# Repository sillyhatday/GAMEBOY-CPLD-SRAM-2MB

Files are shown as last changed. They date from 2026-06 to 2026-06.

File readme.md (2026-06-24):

# GAMEBOY-CPLD-SRAM-2MB

>[!WARNING]
>Current circuit board revision does not include support for the MAX7000 or ATF150x CPLD without bodges.

## Introduction:

This is my take of a CPLD based flash cart for the Gameboy.

The whole project is based from Alex's project from years back. Without that project, I would never have picked this up and spend my time figuring out how to work with CPLDs. I am not a programmer and do not claim to be. Picking up Alex's code I can see how things work with my previous knowledge of how carts operate.

This version uses SRAM like Alex's did originally. As much as I love using FRAM to bring this old technology towards the modern age, it is technically not compatible due to timing and different glue logic requirments. Not to mention it's really expensive new, China sells cheap factory rejects, and on the whole it's a pain in the ass. Embrace SRAM, it's cheap and available. The battery life is not an issue as people want to think, my original Pokemon Red, Blue and Yellow carts are still using the original batteries with over 3v in them after 28 years.

The newest update has been done with the help of AI. I just wanted to get this thing done so it is off my active project list. Even though AI has helped, I have learned a little bit more about how CPLDs work because of it. In the future I'd like to use the knowledge to do another project.

Some reasons to build this project are:

	+ No need for sourcing a donor cartridge
	+ Multi MBC compatibility
	+ Cheaper to build vs a donor cart (initially not, more made, more saved)
	+ No messing with expensive FRAM or dodgy back ally FRAM

>[!IMPORTANT]
> This project is designed with MBC5 functionality as the main priority. Compatibility with MBC1 is added on top, therefore, compatibility is not guaranteed. Super Mario Land 2 & Zelda: Link's Awakening work here, where they have issues running on a normal MBC5 chip. However, Donkey Kong Land does not work. Maybe one day I can create an MBC1 CPLD mapper.

>[!NOTE]
>For updates, see towards the end of the readme

## 🟦 Project State:

### :green_circle: Done

	- Get a cartridge that works well enough
	- Make the Altera 3032A & 3064A both work
	- Fix SRAM problems with MAX7000 and edge case MAX3000
	- Fix this readme after half updating and rage quitting. Remove V2.0 PCB pics.
	- Write draft of instructions for programming Atmel chips

### :yellow_circle: In Progress

	- Do some power tests of carts I have built so far.

### :white_circle: To Do

	- Test flashing Atmel chips in circuit
	- Design some hardware to flash Atmel chips in circuit
	- Update PCB to include solder jumper for different CPLD families.
	- Some issues with SRAM in FlashGBX with Atmel 1502A. Check hardware over & adjust WinCUPL settings.

## 🟨 Prerequisites

	* The full components parts list and cart PCB
	* (Optional) JTAG adaptor PCB
	* Altera USB Blaster or FT232 for JTAG (cheap clones work)
	* Windows PC with Quartus II Programmer, Quartus II Web Edition or OpenOCD
	* GBxCart and related software
 	* Modified Gameboy cart shell or (optional) 3D printed Game Gear cart adaptor
	* Equipment to solder tiny SMD components
	* Skills to solder tiny SMD components reliably

## 🔌 CPLD Information

>[!TIP]
>Information on chosing a CPLD <br>
>[ALTERA PROGRAMMING GUIDE](AlteraProgrammingGuide.md) <br>
>[ATMEL PROGRAMMING GUIDE](AtmelProgrammingGuide.md) <br>
>[CPLD POWER USAGE](CartPowerUse.md) <br>

Prices vary, these are typical.

| Model | Cost x1 | Vendor |
| ----- | --- | --- |
| 3032A: | €1.16 | Aliexpress |
| 3064A: | €1.60 | Aliexpress |
| 7032S: | €1.85 | Aliexpress |
| 1504A: | €1.97 | Mouser |

Depending on the model, the AP2127K-3.3TRG1 may not be needed.

| Model | AP2127K | Jumper |
| ----- | --- | --- |
| 3032A | YES | NO |
| 3064A | YES | NO |
| 7032S | NO | YES |
| 1502A | NO | YES |

## 🟦 Parts List

### Cartridge x1

>[!IMPORTANT]
>When ordering cartridge PCBs, make sure to choose 0.8mm thickness and gold plating. <br>
>Altera MAX3000 & MAX7000 CPLDs are obselete and only found on Aliexpress. I suggest the 3032A. (MAX7000 is a relic at this point). <br>
>If ordering MAX7000, get the S version, otherwise throw your money in a fire. Eg, EPM7032S <br>
>Atmel ATF150x parts can be bought new from reputable sellers. However they are trickier to program for the average person. <br>
>Order FRAM from Aliexpress & eBay at your own risk, they are known to be ***extremely*** unreliable. <br>

| Part No. | Package | Qty |
| --- | --- | --- |
| 29F016 | TSOP48 | 1 |
| IS62C256* | SOIC28 | 1 |
| CPLD** | TQFP44 | 1 |
| AP2127K-3.3TRG1*** | SOT23-5 | 1 |
| TPS3613-01DGSR | 10VSSOP | 1 |
| 2N7002 | SOT23 | 1 |
| Cap 100nF | 0603 | 5 |
| Cap 1uF | 0603 | 1 |
| Res 10K | 0603 | 1 |
| Res 49K9 | 0603 | 1 |
| Res 130K | 0603 | 1 |
| Bat Holder | AliExp | 1 |

**Other alternatives include, but are not limited to: AS6C6256, CY62256, R1LP5256. <br>
***EPM3064A, EPM3032A, EPM7064S, EPM7032S, ATF1504A or ATF1502A. <br>
****See CPLD info*

### JTAG Adaptor

| Part No. | Qty |
| --- | --- |
| DS Lite Cart Conn | 1 |
| USB C USB4125 | 1 |
| Pin Headers | 2x5-P2.54mm |
| GG Adaptor or Shell | 1 |
| USB Blaster | 1 |

>[!TIP]
>Link to [Game Gear Adaptor](https://www.thingiverse.com/thing:5830799)

## Build Photos

CPLDcartcomp

**Different CPLD** <br>
CPLDcartclose

## Update June 2026

I've picked this back up again when I found a PCB laying about. I had to wonder if AI was good enough now to help improve things. It is fortunately.

The previous update I was naive to think programming in C++ was anything like Verilog. I mean it is, but the device being programmed works so differently to other CPU based systems.

The issue that has been plaguing the 7032S & 1504A, is the save RAM functionality. Games would not save, or correctly use the cartridge as work RAM. This was on the Gameboy and cart readers. I tested this over a few carts and the first one kinda worked. It was flaky but saving, yet only on the GB and not the cart reader. There worst problem is that this problem crept into some of the 3032A and 3064A carts also.

This code refactor seems to have fixed all these problems, not only the MAX3000 but the MAX7000 also. As of now, the ATF1504 is untested. I am hopeful that it will work also. Programming those is more complex and I've since forgotten how to do it.

The smaller EPM3032A, EPM7032S & ATF1502 with 32 macro cells are now more than big enough to fit the program, no longer is it so tight. This is thanks to removing the 128KB RAM functionality, reducing the amount of registers required to address that has gained a lot of space. Additional code can be added for more functionality such as moving the FRAM gate logic into the CPLD and making it user programmable with a solder bridge on the PCB.

This is all very nice as the smaller chips tend to use less power than the larger counterparts, even though they use the same quantity of macro cells. I'll add more detailed information on the changes in its own readme.

When the Atmel part is confirmed working, I'll update the rest of the readme to walk though programming those. Ideally the PCB could use a revision to add the FRAM mode jumper and a jumper to bypass the 3.3v regulator when using the MAX7000 and ATF15xx chips. Again, I'll get to that when testing is complete.

## Firmware Versions

| Version | Status | Notes |
| --- | --- | ----- |
| V1.0.0  | Initial | Original code from Alex's blog |
| V1.0.1  | Fix | Removed internal FRAM chip select logic to lower cartridge power consumption 1 to 3% |
| V2.0.0  | Fix | Changed project compiler settings to lower cartridge power consumption 36 to 41% |
| V3.0.0  | Current | AI helper to teach me and structure code better. Use of macro cells more efficient. Logic split into smaller sections. More reliable, cleaner code, better output waveforms (I need to confirm that). |

## 🩷 Links

🔧 Driver Install: https://www.terasic.com.tw/wiki/Intel_USB_Blaster_Driver_Installation_Instructions <br>
⬇️ Driver Download: https://github.com/sudhamshu091/USB-Blaster-Driver-for-DE10-lite <br>
🖨️ Game gear Adaptor: https://www.thingiverse.com/thing:5830799 <br>
⏬ Alt Link Quartus: https://archive.org/details/quartus-iiprogrammer-and-signal-tap-ii-13.1.0.162.7z <br>
🛍️ Inside Gadgets Shop: https://shop.insidegadgets.com <br>
📎 Inside Gadgets GitHub: https://github.com/insidegadgets <br>
📷 Inside Gadgets Insta: https://www.instagram.com/inside.gadgets <br>
🖇️ Bytendo Mods GitHub: https://github.com/bytendomods <br>
🐭 Bucket Mouse: https://github.com/Bucket-Mouse <br>
🛒 Natalie Shop: https://nataliethenerd.com/ <br>
🤓 Natalie GitHub: https://github.com/natalie-lang/natalie <br>

Thanks to Xukkorz, Drew, Jamo, Alex, Deceptive Thinker, Natalie the Nerd & anyone else who I may have forgotten.

## License

This work is licensed under a Creative Commons Attribution-ShareAlike 4.0 International License. You are able to copy and redistribute the material in any medium or format, as well as remix, transform, or build upon the material for any purpose (even commercial) - but you must give appropriate credit, provide a link to the license, and indicate if any changes were made.

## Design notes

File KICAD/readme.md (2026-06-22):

I never uploaded the pcb files wtf. I think these are up to date.

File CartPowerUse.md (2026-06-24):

## 🔌 Cartridge Power:

>[!NOTE]
>I cut the 5V plane coming from the 5v cart pin and bridged it with a 2.2Ω shunt resistor. Voltage was then measured accross the resistor to determine current used.
>These are screen captures from an emulator to show the game locations used for testing more clearly than photographs of the Gameboy screen:

First 4 caps
2nd 4 caps
Stats

## Altera EPM3064A:

| Pokemon Shin Red | Current mA V1.0 | Current mA V1.1 | Current mA V2.0 | Current mA V3.0 |
| --- | --- | --- | --- | --- |
| Intro Animation  | 30.9 | 31 | 17 | 26.4 |
| Title Screen Low | 30.3 | 30.2 | 17.6 | --- |
| Title Screen High | 35.8 | 35.7 | 23.9 | 30.9 |
| Overworld A | 32.7 | 33.1 | 21.3 | 28.4 |
| Overworld B | 30.2 | 30.5 | 18.9 | 26.1 |
| Overworld Talking | 38.7 | 38.9 | 27.6 | 33.6 |
| Pokemon Centre Nurse | 38.6 | 38.7 | 27.4 | 33.6 |
| Battle Scene | 34.8 | 34.8 | 23.3 | 30.3 |
| Pause Menu | 38.5 | 38.5 | 26.7 | 33.2 |
| Pokemon Stats | 38.7 | 38.7 | 27.1 | 33.5 |
| Average | 34.9 | 35.0 | 23.1 | 30.7 |

## Altera EPM3032A:

| Pokemon Shin Red | Current mA V1.0 | Current mA V1.1 | Current mA V2.0 | Current mA V3.0 |
| --- | --- | --- | --- | --- |
| Intro Animation | 26.4 | 25.8 | 15.9 | 17.2 |
| Title Screen Low | 25.9 | 25.1 | 15.6 | --- |
| Title Screen High | 31.8 | 30.1 | 20.9 | 23.9 |
| Overworld A | 29.0 | 28.1 | 18.5 | 20.2 |
| Overworld B | 26.5 | 25.6 | 16.4 | 17.8 |
| Overworld Talking | 34.9 | 34.1 | 24.5 | 26.2 |
| Pokemon Centre Nurse | 34.9 | 34.1 | 24.3 | 26.2 |
| Battle Scene | 31.2 | 30.3 | 20.9 | 22.7 |
| Pause Menu | 34.7 | 33.8 | 24.0 | 25.9 |
| Pokemon Stats | 35.0 | 34.1 | 24.2 | 26.4 |
| Average | 31.0 | 30.1 | 20.5 | 22.9 |

## Altera EPM7032S:

| Pokemon Shin Red | Current mA V1.0 | Current mA V1.1 | Current mA V2.0 | Current mA V3.0 |
| --- | --- | --- | --- | --- |
| Intro Animation | ---- | 34.6 | 21.8 | 20.2 |
| Title Screen Low | ---- | 34.2 | 21.6 | ---- |
| Title Screen High | ---- | 51.0 | 46.4 | 27.8 |
| Overworld A | ---- | 37.1 | 24.9 | 23.7 |
| Overworld B | ---- | 34.7 | 22.7 | 21.2 |
| Overworld Talking | ---- | 52.9 | 41.3 | 30.2 |
| Pokemon Centre Nurse | ---- | 53.0 | 41.3 | 29.7 |
| Battle Scene | ---- | 39.7 | 27.9 | 26.3 |
| Pause Menu | ---- | 42.9 | 30.9 | 29.7 |
| Pokemon Stats | ---- | 43.0 | 30.9 | 30.1 |
| Average | ---- | 42.3 | 31.0 | 26.5 |

## Atmel ATF1502A:

| Pokemon Shin Red | Current mA V1.0 | Current mA V1.1 | Current mA V2.0 | Current mA V3.0 |
| --- | --- | --- | --- | --- |
| Intro Animation | ---- | ---- | 36.8 | 40.0 |
| Title Screen Low | ---- | ---- | 36.6 | ---- |
| Title Screen High | ---- | ---- | 55.9 | 47.7 |
| Overworld A | ---- | ---- | 39.8 | ---- |
| Overworld B | ---- | ---- | 37.6 | ---- |
| Overworld Talking | ---- | ---- | 55.9 | ---- |
| Pokemon Centre Nurse | ---- | ---- | 56.0 | ---- |
| Battle Scene | ---- | ---- | 42.7 | ---- |
| Pause Menu | ---- | ---- | 45.5 | 47.9 |
| Pokemon Stats | ---- | ---- | 46.3 | 48.1 |
| Average | ---- | ---- | 46.0* | 45.9** |

>[!NOTE]
>**Buggy and strange flashing behaviour* <br>
>***RAM refuses to flash properly under sustained writes* <br>

## Summary

I did not expect the MAX3000 chips to get worse with a *better* firmware. It's not a huge difference, but it is there. I also did not expect the MAX7000 to get better! There is obviously some architecture differences that favour the older ***long*** obselete MAX7000 series.

The unfortunate data comes from the Atmel chips. I was hopeful these would be competative with the others as they are the only readily availible items. Not only have I had endless troubles getting save RAM to work properly, the amount of power used is too high. For example, a stock DMG running a stock Pokemon Blue cart uses between 44 - 60mA for the entire console...

The clear winner is the 3032A, with the lowest power use and it also being the cheapest to purchase.

Second place is a tie between the 3064A and 7032S. While the 3064A is the cheaper of the two, the 7032S is better on power. I call it a draw as the 7032S doesn't cost a lot more than the 3064A.

Last place its the 1502A with awful power draw, highest price, harder to program and still not fully working.

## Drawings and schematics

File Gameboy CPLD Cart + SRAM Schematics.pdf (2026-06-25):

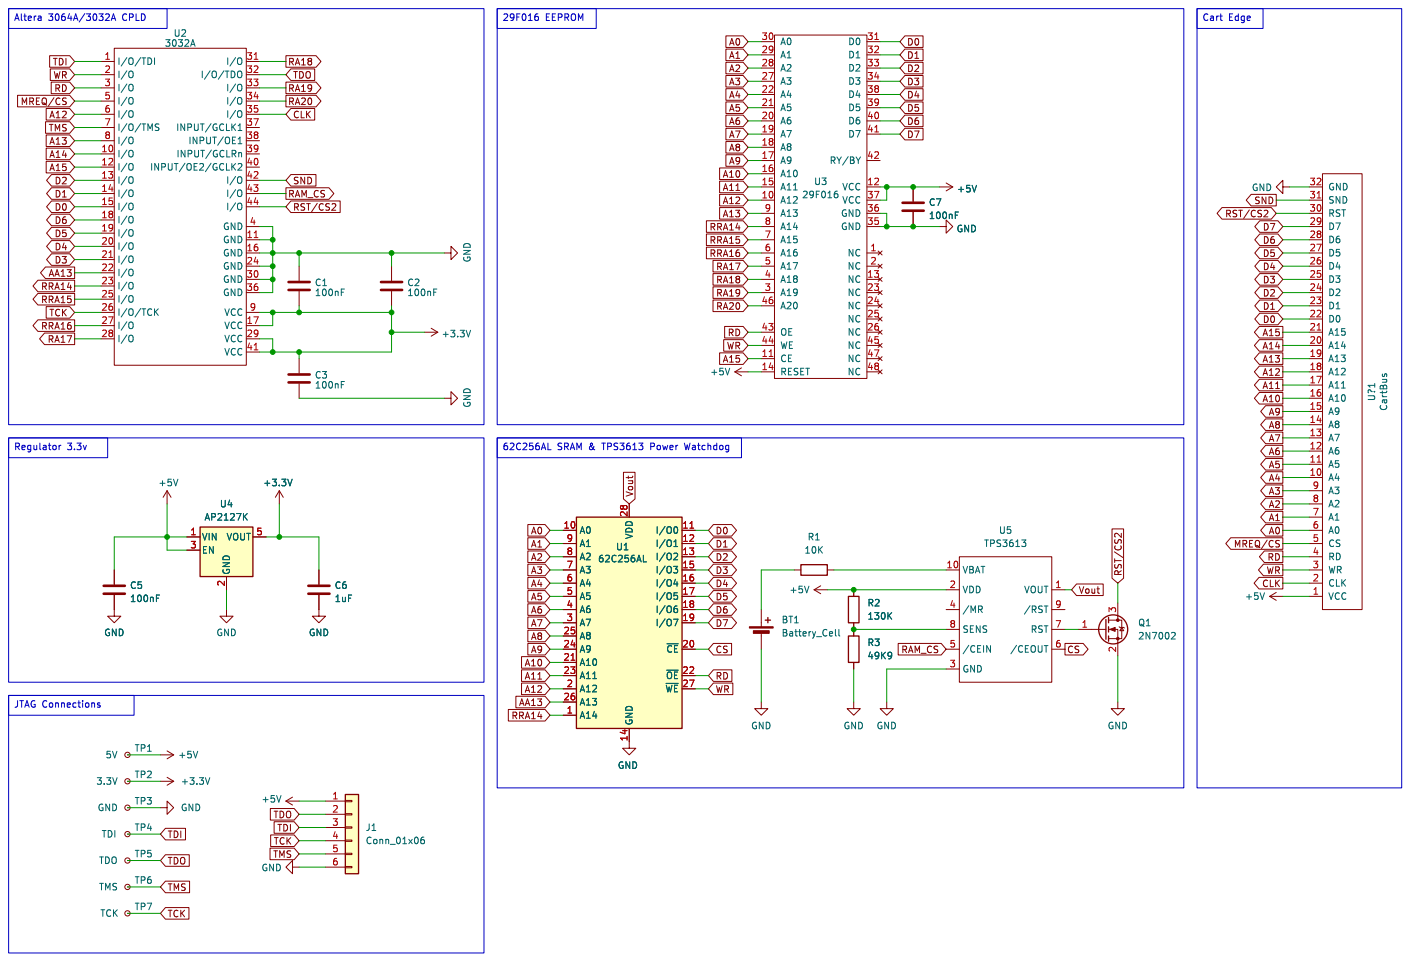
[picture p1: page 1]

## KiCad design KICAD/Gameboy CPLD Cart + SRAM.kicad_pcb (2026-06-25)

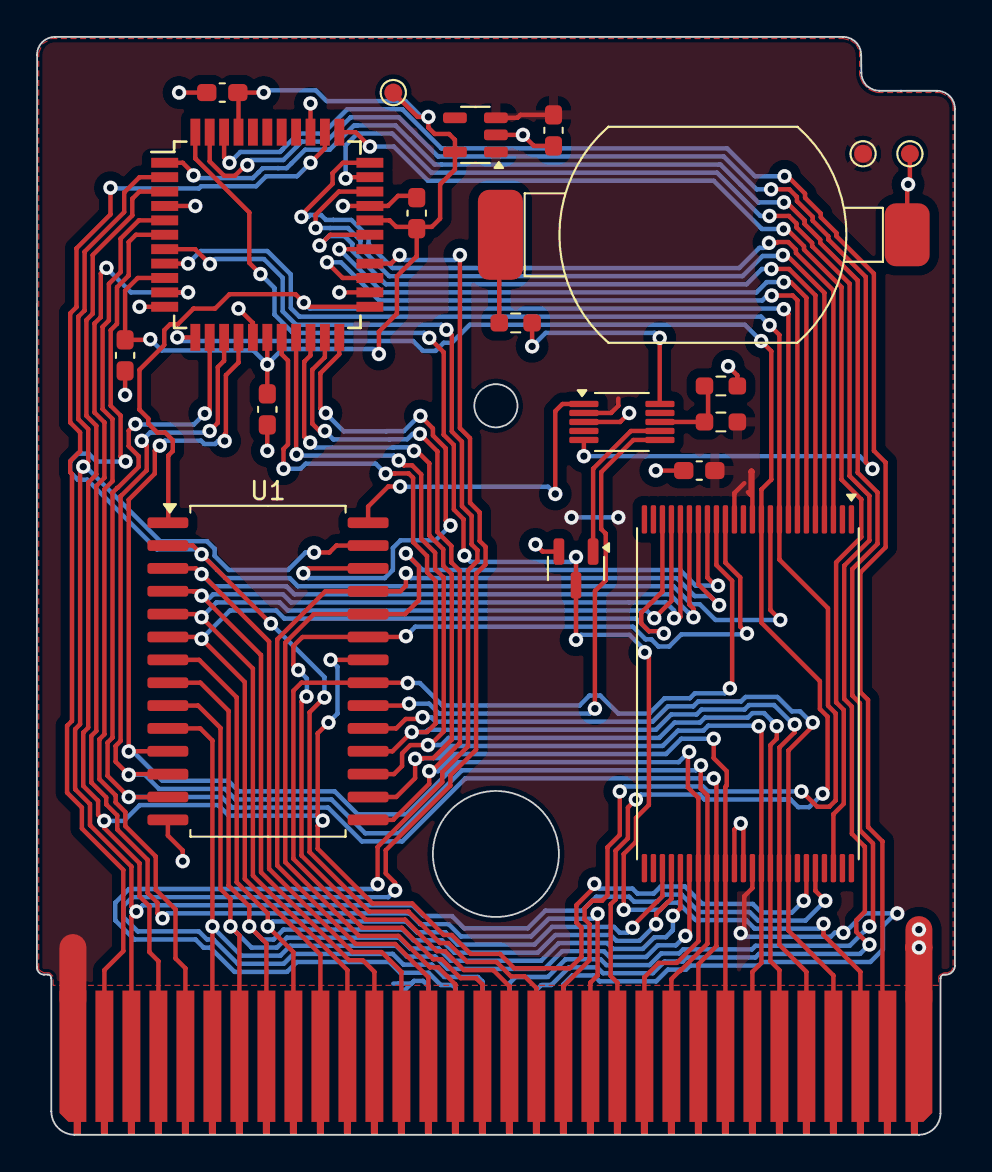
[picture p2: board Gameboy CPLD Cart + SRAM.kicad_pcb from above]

Board: 2 copper layers, 51.0 x 61.0 mm, 21 parts (1 on the bottom side), 52 nets.

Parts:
BT1: Battery_Cell; CR1616 CLIP IN HOLDER
C1, C2, C3, C5, C7: 100nF; C_0603_1608Metric_Pad1.08x0.95mm_HandSolder
C6: 1uF; C_0603_1608Metric_Pad1.08x0.95mm_HandSolder
J1: Conn_01x06; JTAG Cart Edge Connector
Q1: 2N7002; SOT-23
R1: 10K; R_0603_1608Metric_Pad0.98x0.95mm_HandSolder
R2: 130K; R_0603_1608Metric_Pad0.98x0.95mm_HandSolder
R3: 49K9; R_0603_1608Metric_Pad0.98x0.95mm_HandSolder
TP1: 5V; TestPoint_Pad_D1.0mm
TP2: 3.3V; TestPoint_Pad_D1.0mm
TP3: GND; TestPoint_Pad_D1.0mm
U1: 62C256AL; SOP-28_8.4x18.16mm_P1.27mm
U2: 3032A; TQFP-44_10x10mm_P0.8mm
U3: 29F016; TSOP-I-48_18.4x12mm_P0.5mm
U4: AP2127K; SOT-23-5
U5: TPS3613; MSOP-10_3x3mm_P0.5mm
U?1: CartBus; GameBoy_GamePak_DMG-09_P1.50mm_Edge

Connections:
+3.3V: C1.1, C2.1, C3.2, C6.1, TP2.1, U2.9 (VCC), U2.17 (VCC), U2.29 (VCC), U2.41 (VCC), U4.5 (VOUT)
+5V: C5.1, C7.1, J1.1, R2.1, TP1.1, U3.12 (VCC), U3.14 (RESET), U3.37 (VCC~), U4.1 (VIN), U4.3 (EN), U5.2 (VDD), U?1.1 (VCC)
A0: U1.10 (A0), U3.30 (A0~), U?1.6 (A0)
A1: U1.9 (A1), U3.29 (A1), U?1.7 (A1)
A2: U1.8 (A2), U3.28 (A2), U?1.8 (A2)
A3: U1.7 (A3), U3.27 (A3), U?1.9 (A3)
A4: U1.6 (A4), U3.22 (A4), U?1.10 (A4)
A5: U1.5 (A5), U3.21 (A5), U?1.11 (A5)
A6: U1.4 (A6), U3.20 (A6), U?1.12 (A6)
A7: U1.3 (A7), U3.19 (A7), U?1.13 (A7)
A8: U1.25 (A8), U3.18 (A8), U?1.14 (A8)
A9: U1.24 (A9), U3.17 (A9), U?1.15 (A9)
A10: U1.21 (A10), U3.16 (A10), U?1.16 (A10)
A11: U1.23 (A11), U3.15 (A11), U?1.17 (A11)
A12: U1.2 (A12), U2.6 (I/O), U3.10 (A12), U?1.18 (A12)
A13: U2.8 (I/O), U3.9 (A13), U?1.19 (A13)
A14: U2.10 (I/O), U?1.20 (A14)
A15: U2.12 (I/O), U3.11 (CE), U?1.21 (A15)
AA13: U1.26 (A13), U2.22 (I/O)
CLK: U2.35 (I/O), U?1.2 (CLK~)
CS: U1.20 (~CE), U5.6 (/CEOUT)
D0: U1.11 (I/O0), U2.15 (I/O), U3.31 (D0), U?1.22 (D0)
D1: U1.12 (I/O1), U2.14 (I/O), U3.32 (D1), U?1.23 (D1)
D2: U1.13 (I/O2), U2.13 (I/O), U3.33 (D2), U?1.24 (D2)
D3: U1.15 (I/O3), U2.21 (I/O), U3.34 (D3), U?1.25 (D3)
D4: U1.16 (I/O4), U2.20 (I/O), U3.38 (D4), U?1.26 (D4)
D5: U1.17 (I/O5), U2.19 (I/O), U3.39 (D5), U?1.27 (D5)
D6: U1.18 (I/O6), U2.18 (I/O), U3.40 (D6), U?1.28 (D6)
D7: U1.19 (I/O7), U3.41 (D7), U?1.29 (D7)
GND: BT1.2 (-), C1.2, C2.2, C3.1, C5.2, C6.2, C7.2, J1.6, Q1.2 (S), R3.2, TP3.1, U1.14 (GND), U2.4 (GND), U2.11 (GND), U2.16 (GND), U2.24 (GND), U2.30 (GND), U2.36 (GND), U3.35 (GND), U3.36 (GND), U4.2 (GND), U5.3 (GND), U?1.32 (GND)
MREQ/CS: U2.5 (I/O), U?1.5 (CS)
unnamed: BT1.1 (+), R1.1
unnamed: Q1.1 (G), U5.7 (RST)
unnamed: R2.2, R3.1, U5.8 (SENS)
unnamed: R1.2, U5.10 (VBAT)
RA17: U2.28 (I/O), U3.5 (A17)
RA18: U2.31 (I/O), U3.4 (A18)
RA19: U2.33 (I/O), U3.3 (A19)
RA20: U2.34 (I/O), U3.46 (A20)
RAM_CS: U2.43 (I/O), U5.5 (/CEIN)
RD: U1.22 (~OE), U2.3 (I/O), U3.43 (OE~), U?1.4 (RD)
RRA14: U1.1 (A14), U2.23 (I/O), U3.8 (A14)
RRA15: U2.25 (I/O), U3.7 (A15)
RRA16: U2.27 (I/O), U3.6 (A16)
RST/CS2: Q1.3 (D), U2.44 (I/O), U?1.30 (RST)
SND: U2.42 (I/O), U?1.31 (SND)
TCK: J1.4, U2.26 (I/O/TCK)
TDI: J1.3, U2.1 (I/O/TDI)
TDO: J1.2, U2.32 (I/O/TDO)
TMS: J1.5, U2.7 (I/O/TMS)
Vout: U1.28 (VDD), U5.1 (VOUT)
WR: U1.27 (~WE), U2.2 (I/O), U3.44 (WE), U?1.3 (WR)

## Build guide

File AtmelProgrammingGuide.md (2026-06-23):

## Programming Atmel parts (DRAFT)

I'm going to do my best to document this. These Atmel parts are more involved to get working. There is also a save bug with larger save files that needs solving. I figured out how to do this once before and forgot, so spent hours figuring it out again. Nothing I do is ever easy or simple.

Firstly, for programming Atmel parts, Quartus Programmer is of no use. The program used in its place is `OpenOCD`. It's a command line/terminal program that is far from user friendly. It is a powerful tool, that means there are a lot of options to configure. I've bundled these options into a config file to help simplify things.

As with Altera parts, there needs to be some hardware to do the programming. I use a generic FT232H clone from Aliexpress. It was about £3. Right now this is the state of the programmer:

atmelflasher

I plan to do something to make this more user friendly. Firstly, make it so the chips can be flashed in circuit. The issue in making it more user friendly is that there are so many different FT232 clones that I can't make every one of them plug into the JTAG adaptor. I can make a separate board that the ribbon cable can plug into along with the FT232. That is more of the same problem with so many different FT232 clones. Plus, it's another PCB to make to add more expense and complication. I need to think.

>[!WARNING]
>I suggest doing this in Windows and not Linux. On Linux I've had problems talking to the FT232 due to the driver being held by something else. I think it's `brltty` but I gave up solving it.

Download OpenOCD. Move the program to a simple folder path like `C:\openocd` to make things easier when using the command line. Open this folder and go to the `bin` folder inside. This is where some files need to be placed. In here copy `prog.cfg` and the SVF file for the CPLD you are using.

That should be the software setup ready. Check if OpenOCD can talk to the FT232 device. If not, a new driver needs to be installed.

Plug in your FT232 device and connect the CPLD to it (HOWEVER I DECIDE TO HAVE THEM CONNECT) Run the following in the command line:

```
openocd -f interface/ftdi/um232h.cfg -c "transport select jtag" -c "adapter speed 5" -c "init" -c "scan_chain"
```

This is the expected output:

```
xPack Open On-Chip Debugger 0.12.0+dev-02228-ge5888bda3-dirty (2025-10-04-22:44)
Licensed under GNU GPL v2
For bug reports, read
        http://openocd.org/doc/doxygen/bugs.html
adapter speed: 5 kHz
Info : clock speed 5 kHz
Warn : There are no enabled taps.  AUTO PROBING MIGHT NOT WORK!!
Info : JTAG tap: auto0.tap tap/device found: 0x0151203f (mfg: 0x01f (Atmel), part: 0x1512, ver: 0x0)
Warn : AUTO auto0.tap - use "jtag newtap auto0 tap -irlen 3 -expected-id 0x0151203f"
Warn : gdb services need one or more targets defined
   TapName             Enabled  IdCode     Expected   IrLen IrCap IrMask
-- ------------------- -------- ---------- ---------- ----- ----- ------
 0 auto0.tap              Y     0x0151203f 0x00000000     3 0x01  0x03
Info : Listening on port 6666 for tcl connections
Info : Listening on port 4444 for telnet connections
```

You can see the ID code of the part has been found, `0x0151203F`. If there are no devices found, then install the new driver.

>[!NOTE]
>Download Zadig from https://zadig.akeo.ie/, tell it to show all devices. Select your FT232 device, then select libusbk as the driver. Install it and wait, it can take some time. You may want to reboot the system but I should work without. Run the scan again.

If the scan has worked, then everything is ready to program. Run the following:

```
openocd -f interface/ftdi/um232h.cfg -f prog.cfg
```

If it is working then you will see the command line scrolling after each SVF instruction. It's set to program slowly as the FT232 clones are not great and they can vary on how well they handle higher speeds.

That should be it, the Atmel part is programmed. Load the cart into GBXcart and program it with whatever you desire to play.

>[!TIP]
>If you get an ID mismatch error, I think it is because OpenOCD is not up to date with the newest revisions of CPLDs. The SVF files provided are manually edited to correct the expected ID. There is a chance that the CPLD you have is from an older or even a newer revision. In which  case, open the SVF file and edit the ID string to match the one you have being read from the chip. As an example, OpenOCD expects `0x0150203F` as the ID for the `ATF1502AS`, where the ones I have tried return `0x0151203F`. These were bought new from LCSC and should be legitimate parts.

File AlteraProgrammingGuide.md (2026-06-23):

# Programming Guide

>[!TIP]
>For the USB Blaster I prefer the larger version shown below over the smaller version. I'm not sure if it is less reliable or if it's just me being stupid. Either way, up to you.

**Smol** <br>
USB-Blaster-ALTERA-CPLDFPGA-Programmer-1-52150820

**Big** <br>
AliJTAG

>[!IMPORTANT]
>This is a rough guide and you are expected to know how to use a Windows PC, solder SMD parts, hold a pencil, etc.

Get your USB Blaster drivers installed. I used a github repo for the drivers. Install them through device manager. The links below have the details and drivers.

>[!NOTE]
>Driver Installation: https://www.terasic.com.tw/wiki/Intel_USB_Blaster_Driver_Installation_Instructions <br>
>Driver Download: https://github.com/sudhamshu091/USB-Blaster-Driver-for-DE10-lite

>[!TIP]
>Make sure you have good solder joints and that any flux is thoroughly cleaned from IC pins. The JTAG interface seems sensitive and excess flux has caused me issues trying to program.

Make sure to download the programmer software from here or source it yourself if you wish. The install is simple, just click through and wait. I have also uploaded it here:

https://archive.org/details/quartus-iiprogrammer-and-signal-tap-ii-13.1.0.162.7z

Insert your assembled cart into the JTAG adaptor using the 3D printed shim so that the cart can be inserted upside down. (The back side with the 6 cart edge pins).

>[!TIP]
>If you don’t have access to a 3D printer, you can make one by cutting around 15mm off the bottom of a cartridge shell back piece.

Launch the Quartus II Programmer software you just installed.

quartus main page

Make sure that the USB Blaster is detected and selected in Quartus. If not click “Hardware Setup…” and find it.

quartus blaster select

Once selected select the POF file for the CPLD you are using, 3064A, 3032A, 7032S or 7064S.

quartus blaster selected

If the CPLD is not yet proven, it is possible that it is already programmed from its previous life. Click “Erase” and press start. If your JTAG is connected properly and working, it should erase quickly. If problems continue, recheck JTAG connections, solder joints and flux residue. If things still do not work, then the CPLD is already programmed with JTAG disabled (requiring a professional programmer) or it is damaged.

Erasing is not required as this is done automaticall when programming. I like to do an erase on new CPLDs to prove the JTAG chain is working and the programming file isn't causing problems (wrong file, corrupted).

quartus erase

Once erased, it is worth doing a “Blank-Check” to be sure that the erase worked correctly.

quartus blank check

Finally time to program the CPLD. Check “Program/Configure” and “Verify”, then click start for the last time. It should take about 2 seconds.

>[!TIP]
>If you have any trouble, check your JTAG connections, reflow the CPLD, make sure the adaptor board is powered, clean off flux residue, check the correct POF file is selected, check the POF file is not corrupt.

quartus prog

The mapper is now programmed. You can put this stuff away for good unless you want to keep up with firmware update or program more cartridges.

Now move over to your GBxCart software and test it out.

>[!NOTE]
>Any problems in GBxCart are more likely an issue with flash chip soldering, or hidden solder between CPLD pins, than issues with the CPLD program. Any issues with programming game saves is the problem of cheap dead FRAM.

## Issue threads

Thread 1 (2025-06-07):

Detailed BOM or Schematics

xythobuz, 2025-06-07:
I'd like to build this cartridge. The gerber files in the release are fine to order PCBs, and the BOM in the Readme is enough to order the parts. But for assembly I'm missing the part names in the BOM. Which resistor and capacitor needs to go where?

Also, would you be willing to share the schematics or KiCad files as well? 😃

Thanks for the great project!

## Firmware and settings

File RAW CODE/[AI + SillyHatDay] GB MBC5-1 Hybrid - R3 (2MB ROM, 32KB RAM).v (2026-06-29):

module MBC5_CPLD (
    reset,
    inputAddress,
    inputData,
    inputCE,
    inputWR,
    inputRD,
    highAddress,
    ramCE
);

// ============================================================
// Port Declarations
// ============================================================
input           reset;
input   [3:0]   inputAddress;   // a15-a12
input   [6:0]   inputData;      // d6-d0
input           inputCE;
input           inputWR;
input           inputRD;

output  [7:0]   highAddress;    // a20-a13
output          ramCE;

// ============================================================
// Internal Registers
// ============================================================
reg [7:0]   highAddress;
reg [6:0]   romBank;
reg [1:0]   ramBank;
reg         ramEnabled;
reg         mbc1Detect303FOn;
reg         mbc1Detected607F;
reg         mbc3or5Locked;

// ============================================================
// Convenience wires
// ============================================================
wire busActive  = (!inputRD || !inputWR);   // any bus activity
wire isWrite    = (!inputWR && inputRD && inputCE); // clean write strobe
wire isRamArea  = (inputAddress == 4'hA || inputAddress == 4'hB);
wire isRomLow   = (inputAddress <= 4'd3);   // 0x0000-3FFF
wire isRomHigh  = (inputAddress >= 4'd4 && inputAddress <= 4'd7); // 0x4000-7FFF

// ============================================================
// ramCE — purely combinatorial, separate block
// Keeps CE clean regardless of clock signal behaviour
// ============================================================
reg ramCE;

always @ (*) begin
    if (ramEnabled && isRamArea && busActive) begin
        ramCE = inputCE;
    end
    else begin
        ramCE = 1'b1; // deasserted (active low, so high = disabled)
    end
end

// ============================================================
// highAddress — combinatorial, depends on address + bank regs
// ============================================================
always @ (*) begin
    if (isRamArea && ramEnabled && busActive) begin
        // RAM access: output ram bank on lower address bits
        highAddress = {6'b0, ramBank};
    end
    else if (busActive && isRomLow) begin
        // ROM bank 0 window: always physical bank 0
        highAddress = 8'b0;
    end
    else if (busActive && isRomHigh) begin
        // ROM bank 1+ window: shift romBank up to a14
        highAddress = (romBank << 1);
    end
    else begin
        highAddress = 8'b0;
    end
end

// ============================================================
// Registered state — resets and bank register writes
// Triggered on control signals + address + data
// ============================================================
always @ (*) begin

    if (!reset) begin
        romBank             <= 7'd1;
        ramBank             <= 2'd0;
        ramEnabled          <= 1'b0;
        mbc1Detect303FOn    <= 1'b0;
        mbc1Detected607F    <= 1'b0;
        mbc3or5Locked       <= 1'b0;
    end
    else begin

        // --------------------------------------------------------
        // 0x0000-1FFF — RAM Enable register
        // Write 0x?A to enable, anything else disables
        // --------------------------------------------------------
        if ((inputAddress == 4'd0 || inputAddress == 4'd1) && isWrite) begin
            ramEnabled <= (inputData[3:0] == 4'hA) ? 1'b1 : 1'b0;
        end

        // --------------------------------------------------------
        // 0x2000-3FFF — ROM Bank Number low 7 bits
        // MBC1 detection: if data=0 written here, note it
        // --------------------------------------------------------
        if ((inputAddress == 4'd2 ||
            (inputAddress == 4'd3 && mbc1Detect303FOn)) && isWrite) begin
            if (inputData == 7'd0) begin
                romBank          <= 7'd1; // MBC5 allows bank 0, keep as 1 for safety
                mbc1Detect303FOn <= 1'b1;
            end
            else begin
                if (inputData >= 7'd32) begin
                    mbc3or5Locked <= 1'b1;
                end
                romBank <= inputData;
            end
        end

        // --------------------------------------------------------
        // 0x4000-5FFF — RAM Bank Number
        // Ignored if MBC1 detected and not MBC3/5
        // --------------------------------------------------------
        if ((inputAddress == 4'd4 || inputAddress == 4'd5) && isWrite) begin
            if (!(mbc1Detect303FOn && mbc1Detected607F && !mbc3or5Locked)) begin
                ramBank <= inputData[1:0];
            end
        end

        // --------------------------------------------------------
        // 0x6000-7FFF — MBC1 ROM/RAM mode detection
        // --------------------------------------------------------
        if ((inputAddress == 4'd6 || inputAddress == 4'd7) && isWrite) begin
            mbc1Detected607F <= 1'b1;
        end

    end
end

endmodule
